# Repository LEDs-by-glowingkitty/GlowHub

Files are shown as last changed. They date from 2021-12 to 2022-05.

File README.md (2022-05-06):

### Warning:

This project is currently not under active development and the PCB prototype didn't work as expected. But feel free to further improve and fix this project or get inspiration from it for your own projects.

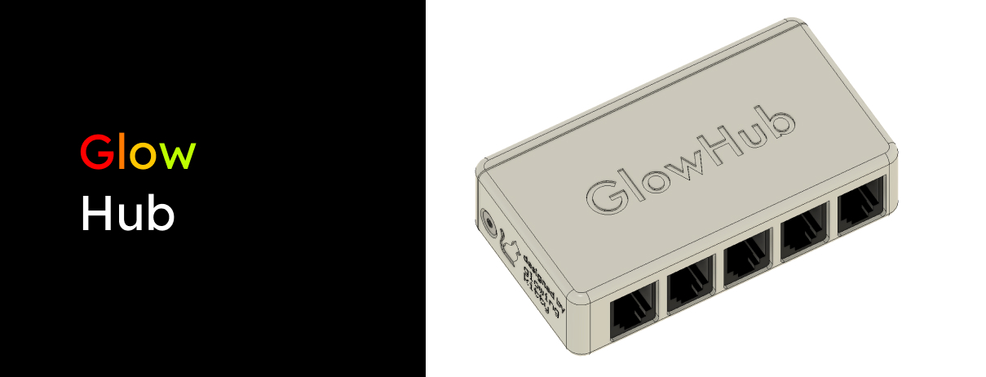
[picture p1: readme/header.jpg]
GlowHub


Control up to 8 LED lamps with a single GlowHub, all glowing perfectly in sync! (or control them separately) Just connect the LED lamps with an RJ11 cable to one of the OUT ports, connect GlowCore to power and you are ready to go!

## Links

- [3D models](https://grabcad.com/library/glowhub-1)
- [PCB files](https://github.com/glowingkitty/GlowHub/tree/main/GlowHubPCB)

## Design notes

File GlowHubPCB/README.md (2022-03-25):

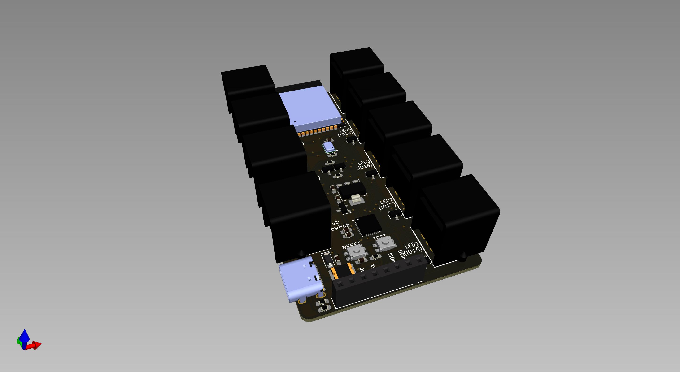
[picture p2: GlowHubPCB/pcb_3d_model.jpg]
GlowHubPCB


# GlowHubPCB

The PCB for GlowHub, to control up to 8 LED lamps at the same time.

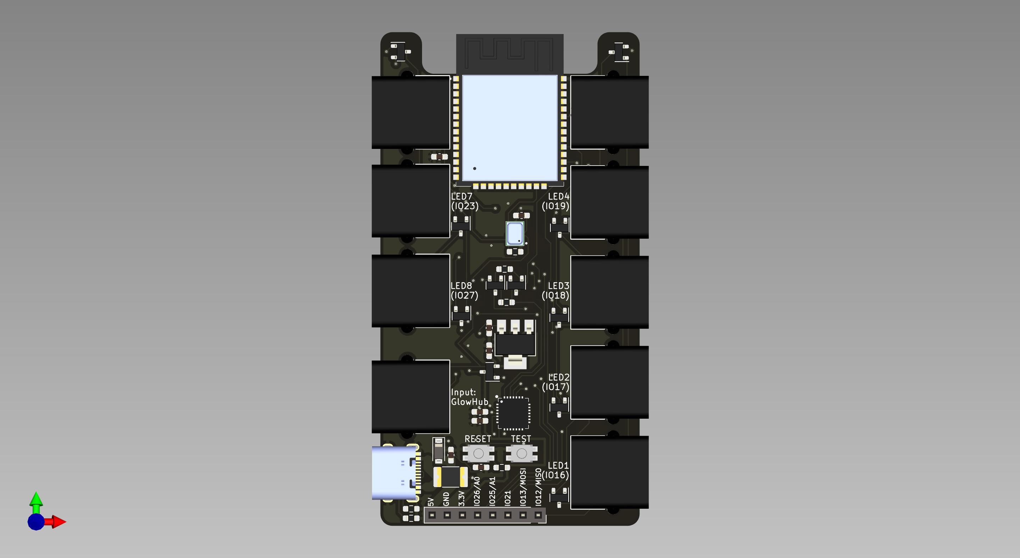
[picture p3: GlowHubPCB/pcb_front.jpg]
GlowHubPCB

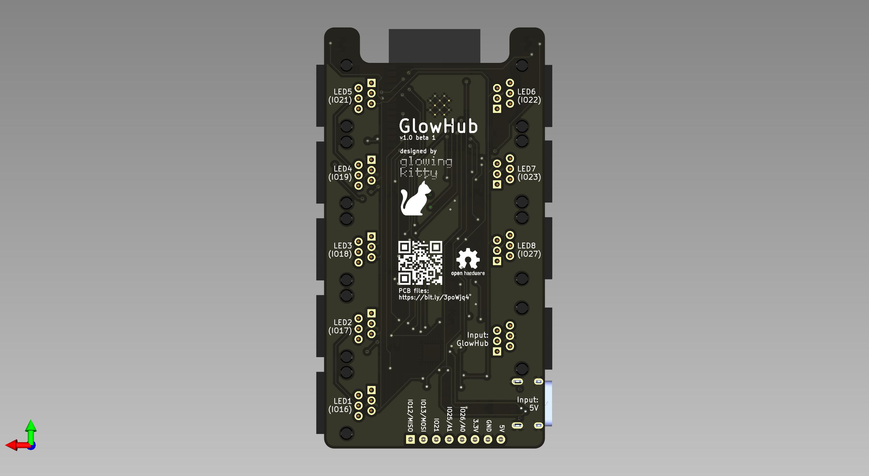
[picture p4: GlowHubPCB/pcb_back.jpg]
GlowHubPCB


## Links

- [Schematic](https://github.com/glowingkitty/GlowHub/blob/main/GlowHubPCB/GlowHubPCB.pdf)
- [Interactive BOM](https://htmlpreview.github.io/?https://github.com/glowingkitty/GlowHub/blob/main/GlowHubPCB/bom/ibom.html)
- [PCB stencils](https://github.com/glowingkitty/GlowHub/blob/main/GlowHubPCB/PCB%20stencils)

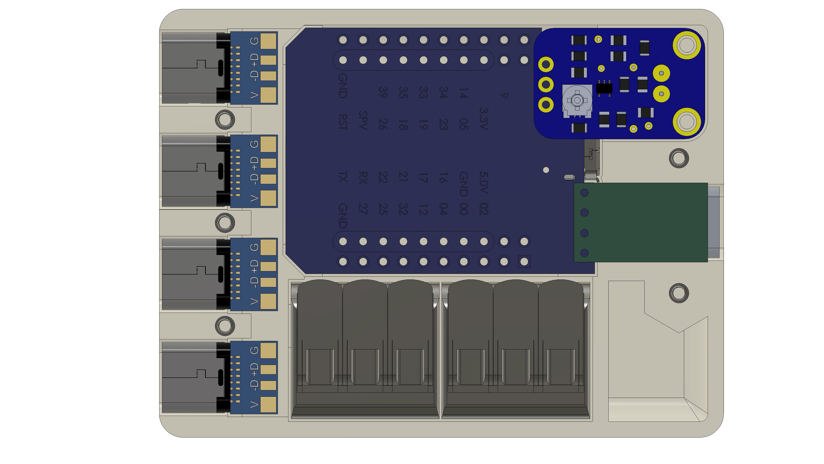
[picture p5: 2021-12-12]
readme/glowhub_electronics.png

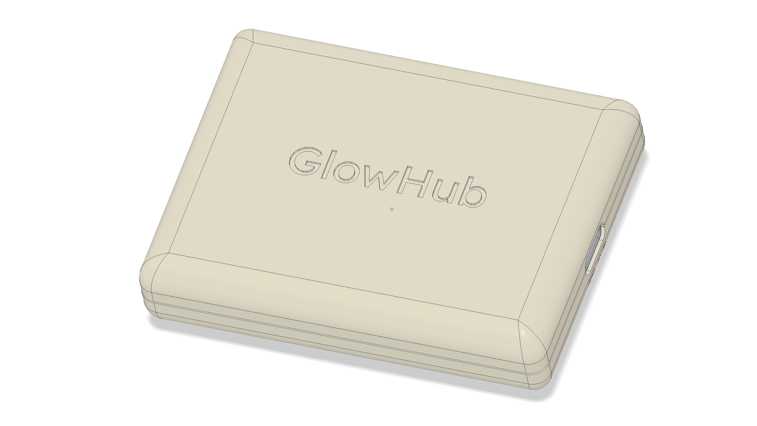
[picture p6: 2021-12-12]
glowhub_image.png

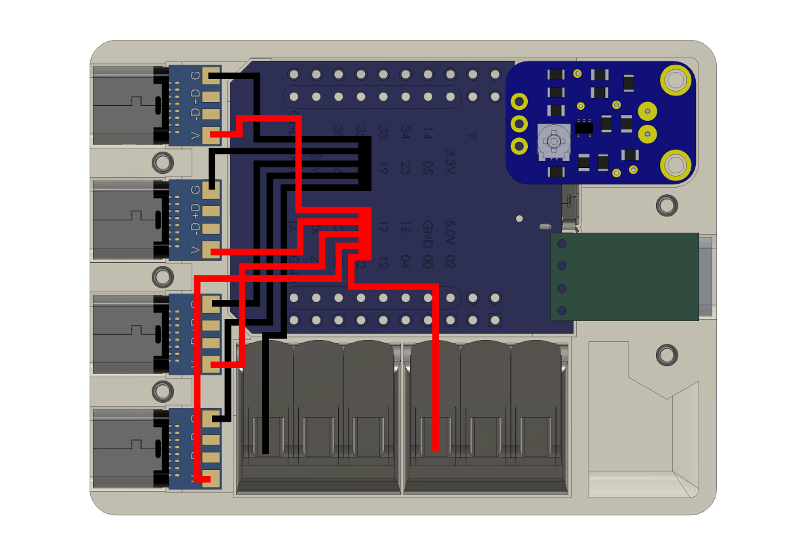
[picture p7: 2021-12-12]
readme/wires_leds_to_wago.jpg

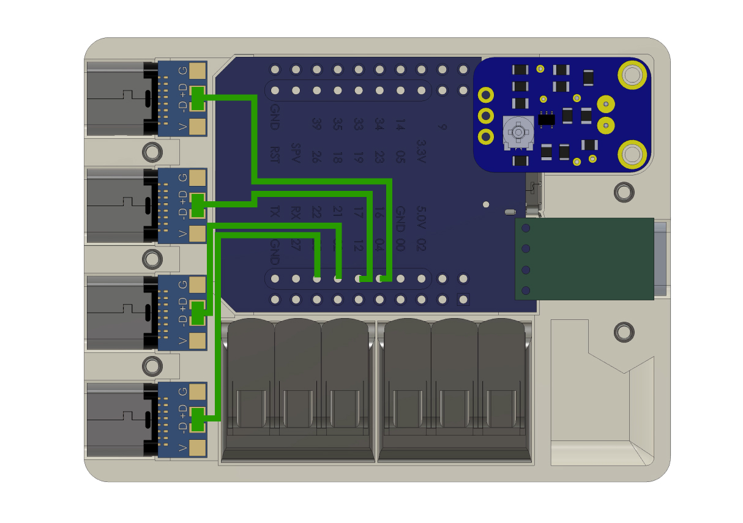
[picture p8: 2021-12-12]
readme/wires_leds_to_esp32.jpg

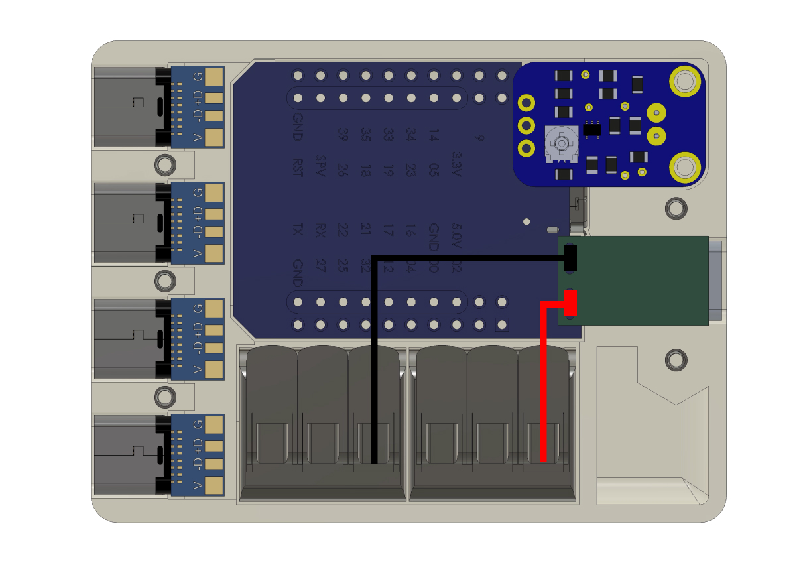
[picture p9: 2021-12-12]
readme/wires_usb_c_pd_to_wago.jpg

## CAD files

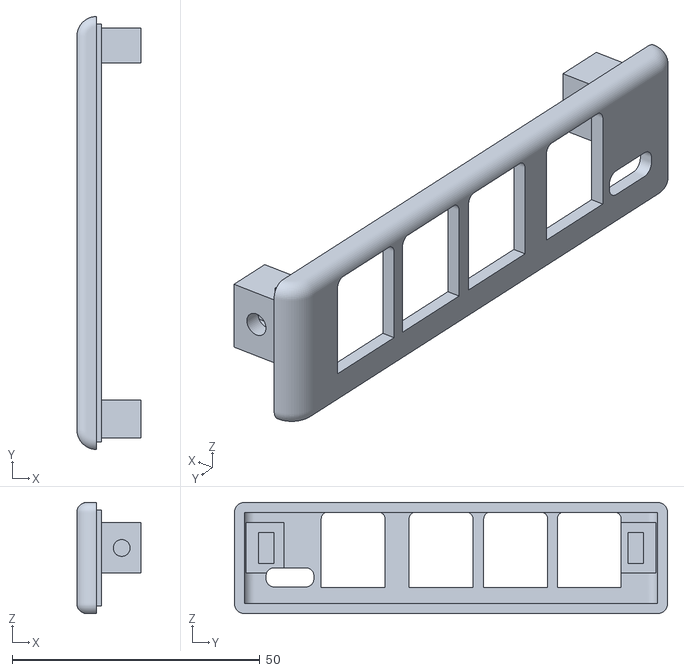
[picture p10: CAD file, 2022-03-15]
3d printed parts/cover.stl
13.0 x 87.5 x 22.4

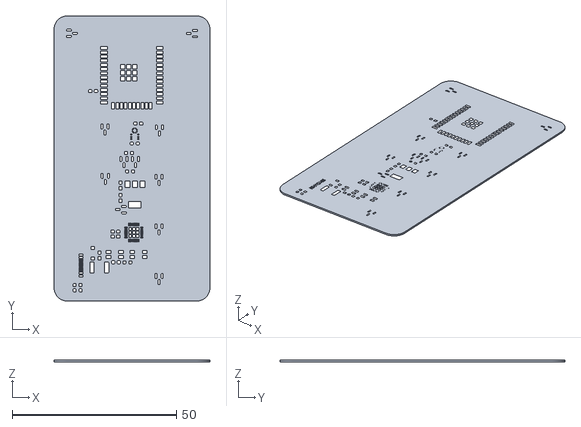
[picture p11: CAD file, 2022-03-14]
GlowHubPCB/PCB stencils/3D printed/stencil.stl
47.4 x 86.8 x 0.5

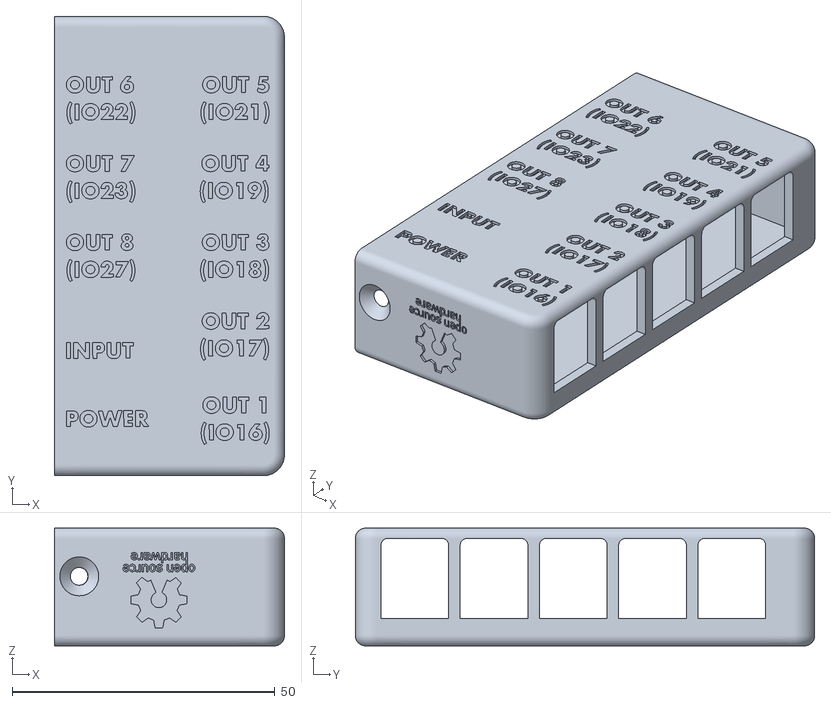
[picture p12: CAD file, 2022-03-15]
3d printed parts/case.stl
43.8 x 87.5 x 22.4

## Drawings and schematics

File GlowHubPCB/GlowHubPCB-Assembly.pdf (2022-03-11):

(IO19) 1 | 2 | 3

A

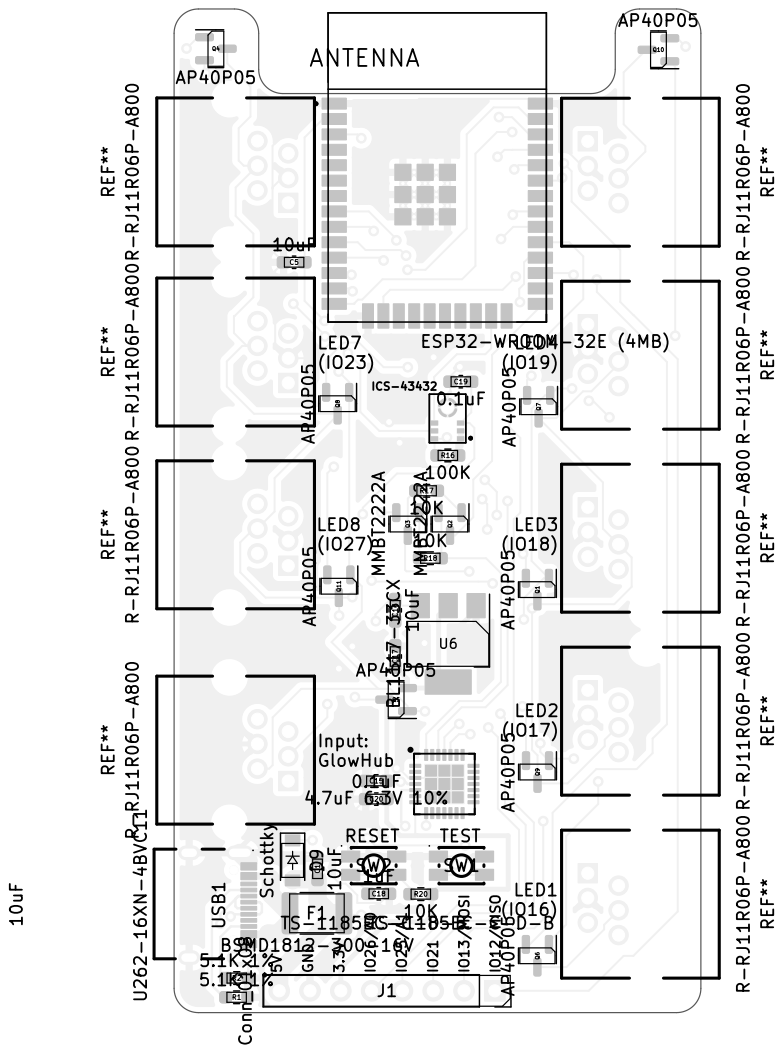
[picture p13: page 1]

1 | 2 | 3

A

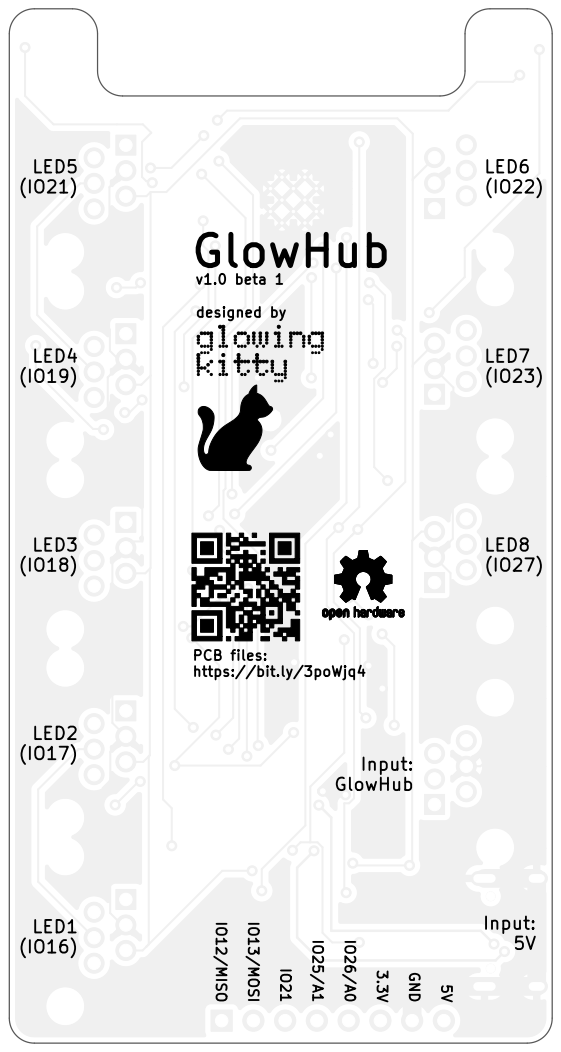
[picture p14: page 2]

PCB files: https://bit.ly/3poWjq4

5V 3.3V GND IO25/A1 IO26/A0 IO21 IO12/MISO IO13/MOSI Input: 5V

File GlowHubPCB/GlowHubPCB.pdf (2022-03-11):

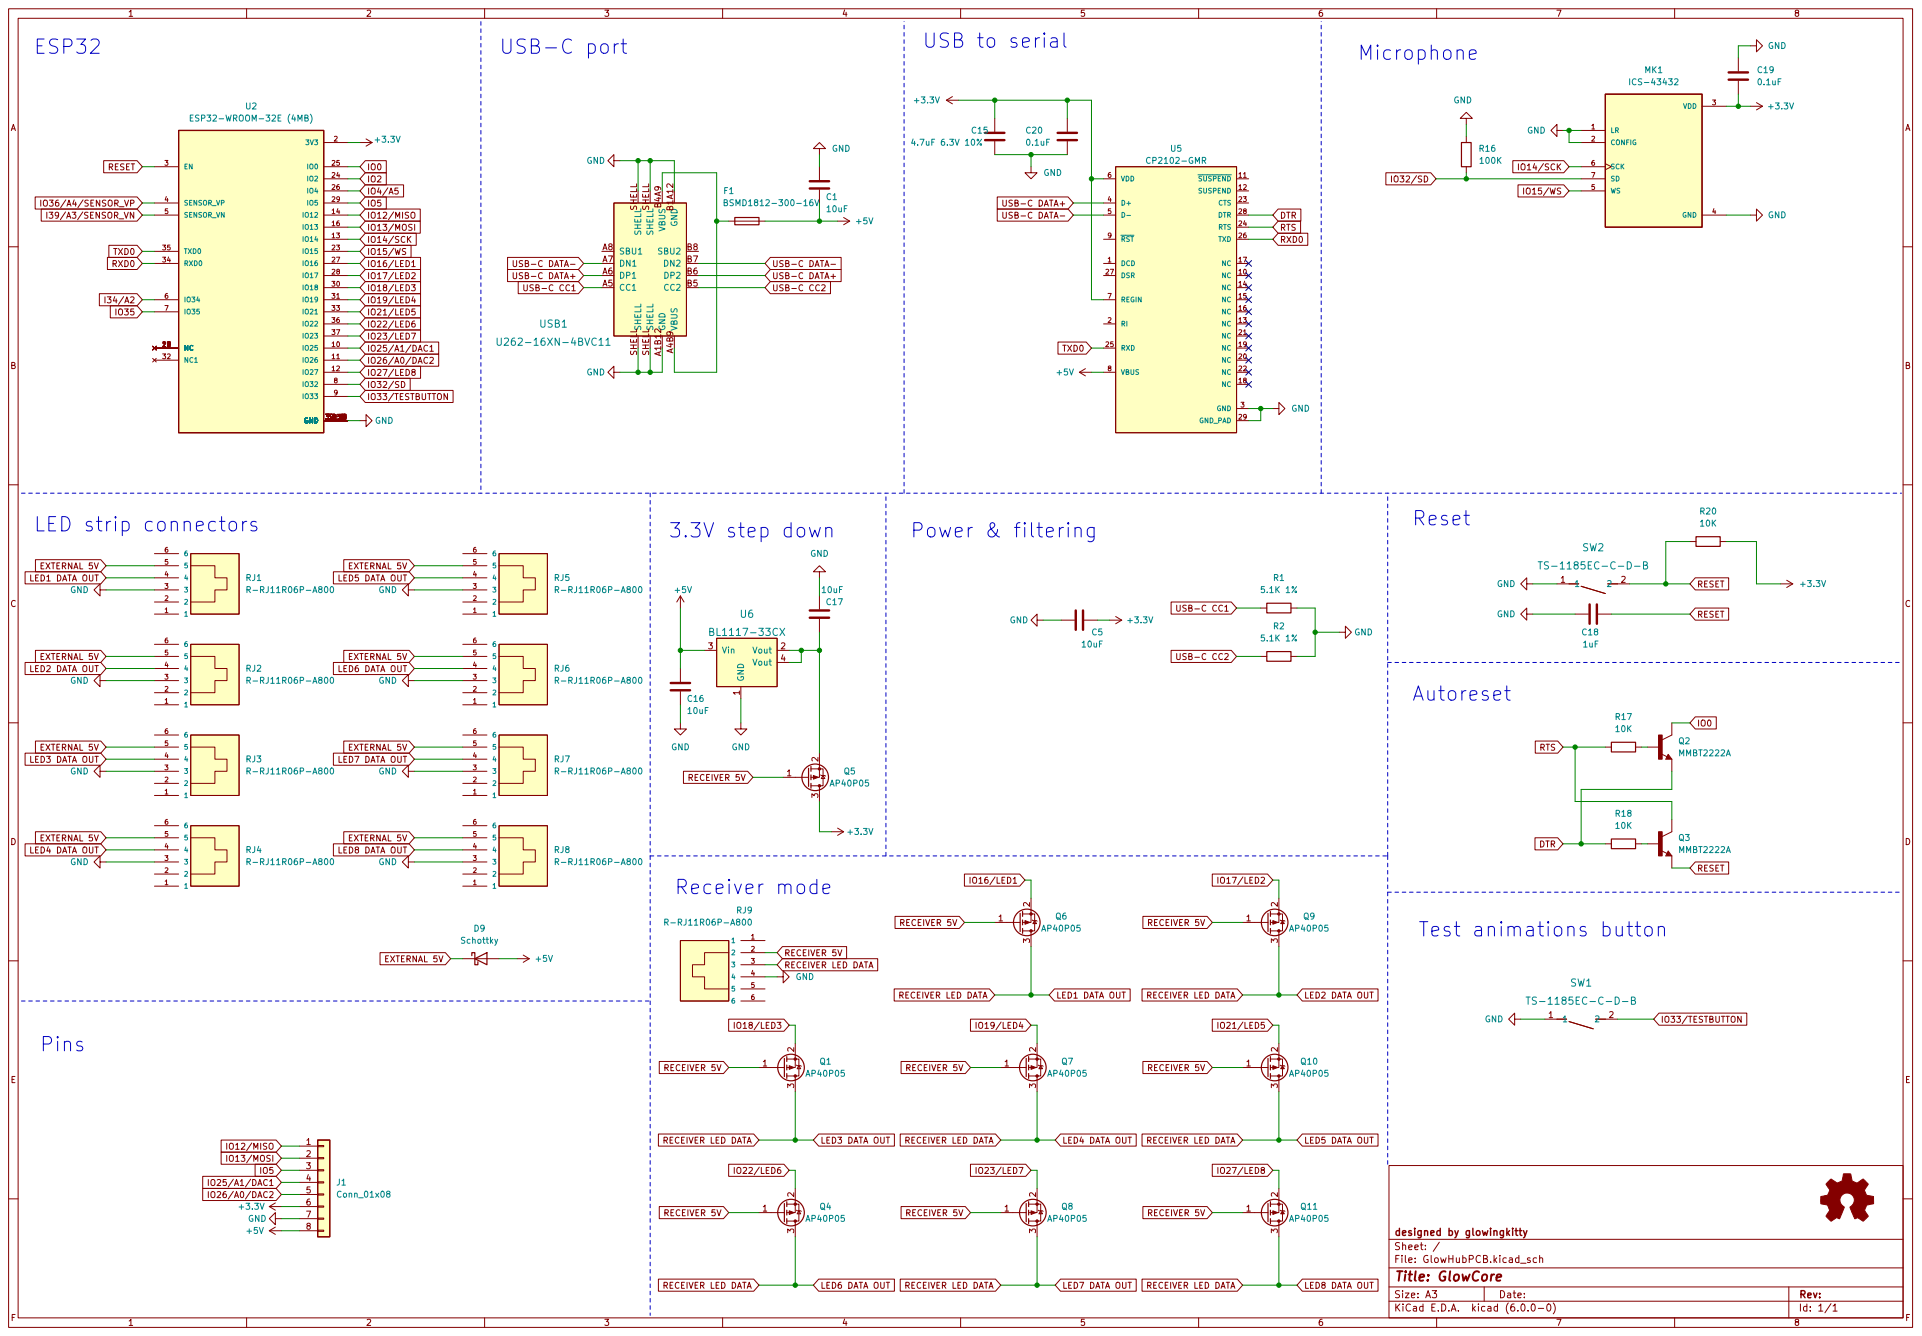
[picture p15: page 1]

Microphone USB to serial

File: GlowHubPCB.kicad_sch Sheet: / designed by glowingkitty GND

IO23/LED7 RECEIVER LED DATA RECEIVER LED DATA RECEIVER 5V Pins

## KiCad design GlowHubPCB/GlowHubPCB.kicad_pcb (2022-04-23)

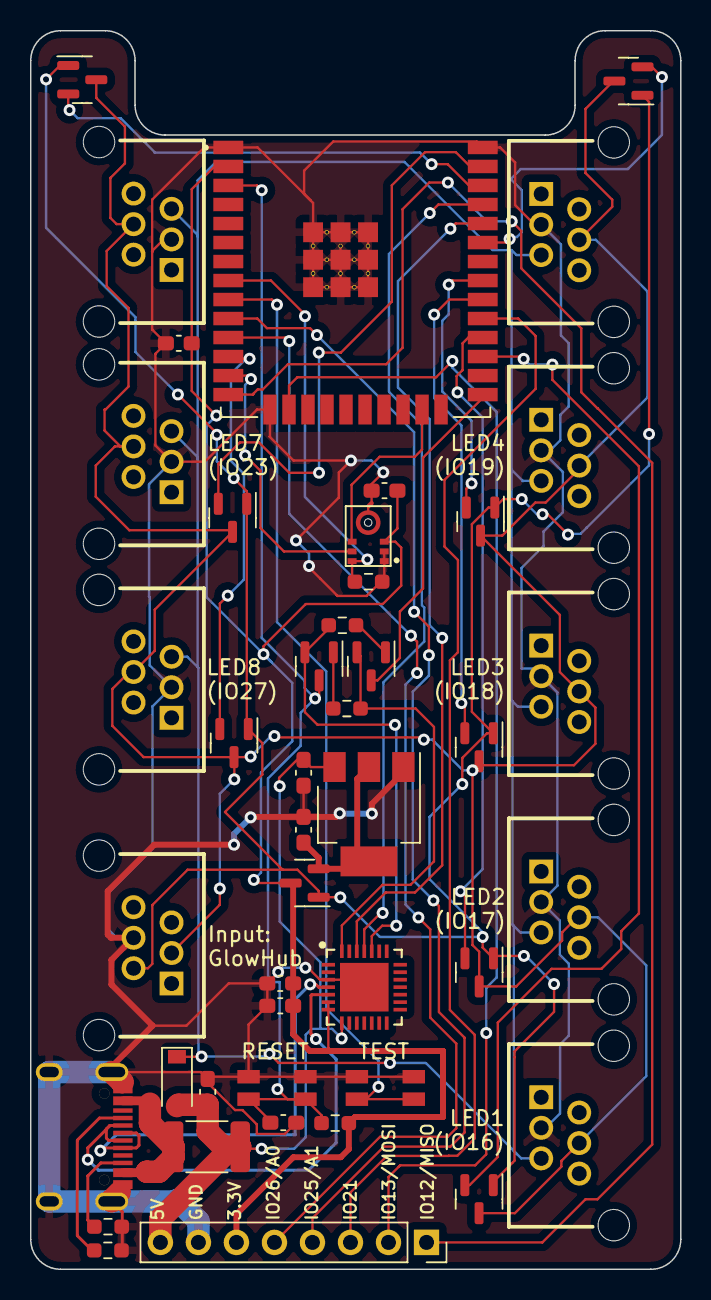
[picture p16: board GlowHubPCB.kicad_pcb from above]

Board: 2 copper layers, 43.4 x 82.8 mm, 44 parts (0 on the bottom side), 37 nets.

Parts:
C1, C5, C16, C17: 10uF; C_0603_1608Metric_Pad1.08x0.95mm_HandSolder
C15: 4.7uF 6.3V 10%; C_0603_1608Metric_Pad1.08x0.95mm_HandSolder
C18: 1uF; C_0603_1608Metric_Pad1.08x0.95mm_HandSolder
C19, C20: 0.1uF; C_0603_1608Metric_Pad1.08x0.95mm_HandSolder
D9: Schottky; D_SOD-123
F1: BSMD1812-300-16V; Fuse_1812_4532Metric_Pad1.30x3.40mm_HandSolder
J1: Conn_01x08; PinSocket_1x08_P2.54mm_Vertical
MK1: ICS-43432; MIC_ICS-43432
Q1, Q4, Q5, Q6, Q7, Q8, Q9, Q10, Q11: AP40P05; SOT-23
Q2, Q3: MMBT2222A; SOT-23
R1, R2: 5.1K 1%; R_0603_1608Metric_Pad0.98x0.95mm_HandSolder
R16: 100K; R_0603_1608Metric_Pad0.98x0.95mm_HandSolder
R17, R18, R20: 10K; R_0603_1608Metric_Pad0.98x0.95mm_HandSolder
RJ1, RJ2, RJ3, RJ4, RJ5, RJ6, RJ7, RJ8, RJ9: R-RJ11R06P-A800
SW1, SW2: TS-1185EC-C-D-B
U2: ESP32-WROOM-32E (4MB); MODULE_ESP32-WROOM-32E_(16MB)
U5: CP2102-GMR
U6: BL1117-33CX; SOT-223
USB1: U262-16XN-4BVC11; USB-3.1-SMD_U262-161N-4BVC11

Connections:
+3V3: C5.1, C15.2, C19.2, C20.1, J1.6, MK1.3 (VDD), Q5.3 (D), R20.2, U2.2 (3V3), U5.6 (VDD), U5.7 (REGIN)
+5V: C1.1, C16.2, D9.2 (A), F1.2, J1.8, U5.8 (VBUS), U6.3 (Vin)
DTR: Q2.2, R18.1, U5.28 (DTR)
EXTERNAL 5V: D9.1 (K), RJ1.5, RJ2.5, RJ3.5, RJ4.5, RJ5.5, RJ6.5, RJ7.5, RJ8.5
GND: C1.2, C5.2, C15.1, C16.1, C17.1, C18.1, C19.1, C20.2, J1.7, MK1.1 (LR), MK1.2 (CONFIG), MK1.4 (GND), R1.1, R2.1, R16.2, RJ1.3, RJ2.3, RJ3.3, RJ4.3, RJ5.3, RJ6.3, RJ7.3, RJ8.3, RJ9.4, SW1.1, SW2.1, U2.1 (GND), U2.15 (GND), U2.38 (GND), U2.39_1 (GND), U2.39_2 (GND), U2.39_3 (GND), U2.39_4 (GND), U2.39_5 (GND), U2.39_6 (GND), U2.39_7 (GND), U2.39_8 (GND), U2.39_9 (GND), U2.39_10 (GND), U2.39_11 (GND), U2.39_12 (GND), U2.39_13 (GND), U2.39_14 (GND), U2.39_15 (GND), U2.39_16 (GND), U2.39_17 (GND), U2.39_18 (GND), U2.39_19 (GND), U2.39_20 (GND), U2.39_21 (GND), U5.3 (GND), U5.29 (GND_PAD), U6.1 (GND), USB1.A1B12 (GND), USB1.B1A12 (GND), USB1.SHELL
IO0: Q2.3, U2.25 (IO0)
IO5: J1.3, U2.29 (IO5)
IO12/MISO: J1.1, U2.14 (IO12)
IO13/MOSI: J1.2, U2.16 (IO13)
IO14/SCK: MK1.6 (SCK), U2.13 (IO14)
IO15/WS: MK1.5 (WS), U2.23 (IO15)
IO16/LED1: Q6.2 (S), U2.27 (IO16)
IO17/LED2: Q9.2 (S), U2.28 (IO17)
IO18/LED3: Q1.2 (S), U2.30 (IO18)
IO19/LED4: Q7.2 (S), U2.31 (IO19)
IO21/LED5: Q10.2 (S), U2.33 (IO21)
IO22/LED6: Q4.2 (S), U2.36 (IO22)
IO23/LED7: Q8.2 (S), U2.37 (IO23)
IO25/A1/DAC1: J1.4, U2.10 (IO25)
IO26/A0/DAC2: J1.5, U2.11 (IO26)
IO27/LED8: Q11.2 (S), U2.12 (IO27)
IO32/SD: MK1.7 (SD), R16.1, U2.8 (IO32)
IO33/TESTBUTTON: SW1.2, U2.9 (IO33)
LED1 DATA OUT: Q1.3 (D), Q4.3 (D), Q6.3 (D), Q7.3 (D), Q8.3 (D), Q9.3 (D), Q10.3 (D), Q11.3 (D), RJ1.4, RJ2.4, RJ3.4, RJ4.4, RJ5.4, RJ6.4, RJ7.4, RJ8.4, RJ9.3
unnamed: C17.2, Q5.2 (S), U6.2 (Vout), U6.4 (Vout)
unnamed: F1.1, USB1.A4B9 (VBUS), USB1.B4A9 (VBUS)
unnamed: Q2.1, R17.2
unnamed: Q3.1, R18.2
RECEIVER 5V: Q1.1 (G), Q4.1 (G), Q5.1 (G), Q6.1 (G), Q7.1 (G), Q8.1 (G), Q9.1 (G), Q10.1 (G), Q11.1 (G), RJ9.2
RESET: C18.2, Q3.3, R20.1, SW2.2, U2.3 (EN)
RTS: Q3.2, R17.1, U5.24 (RTS)
RXD0: U2.34 (RXD0), U5.26 (TXD)
TXD0: U2.35 (TXD0), U5.25 (RXD)
USB-C CC1: R1.2, USB1.A5 (CC1)
USB-C CC2: R2.2, USB1.B5 (CC2)
USB-C DATA+: U5.4 (D+), USB1.A6 (DP1), USB1.B6 (DP2)
USB-C DATA-: U5.5 (D-), USB1.A7 (DN1), USB1.B7 (DN2)

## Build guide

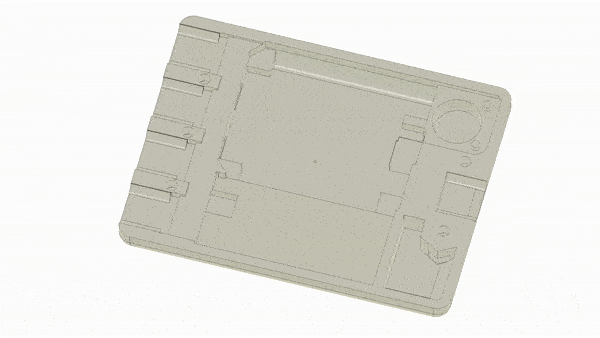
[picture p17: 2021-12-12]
readme/build_1_add_nuts.gif

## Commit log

2021-12-10 added case v1
    [bottom case.3mf, bottom case.stl, top case.3mf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]
2022-02-28 started working on new GlowHub PCB
    [GlowHubPCB.kicad_pcb, GlowHubPCB.kicad_sch]
2022-02-28 added qr code to pcb
    [GlowHubPCB.kicad_pcb]
2022-03-11 added GlowHub PCB prototype
    [GlowHubPCB-CuBottom.gbr, GlowHubPCB-CuTop.gbr, GlowHubPCB-EdgeCuts.gbr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]
2022-03-14 added stencil
    [stencil.stl]
2022-03-15 added redesigned case
    [GlowHubPCB.kicad_pcb, bottom case.3mf, bottom case.stl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]
2022-03-17 added link to 3d models and pcb files
2022-03-25 added pcb stencils
    [GlowHubPCB.kicad_pcb, stencil.stl]
2022-03-26 added 3d printed case
2022-04-23 updated pcb design (in progress)
    [GlowHubPCB.kicad_pcb, GlowHubPCB.kicad_sch]
